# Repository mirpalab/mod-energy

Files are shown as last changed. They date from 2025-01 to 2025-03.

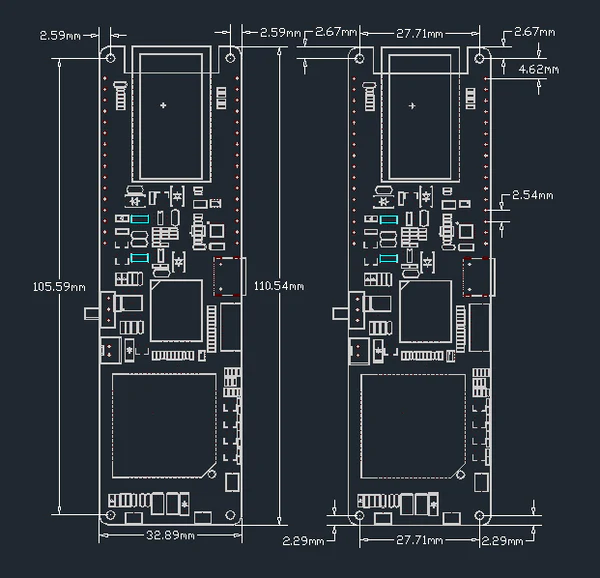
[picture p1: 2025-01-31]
images/quote esp32.png

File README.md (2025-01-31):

Ciò che si trova qui è scritto e gestito dal MIRPALab.

Viene fornito "così com'è", senza alcuna garanzia espressa o implicita di alcun tipo, incluse ma non limitate alle garanzie di commerciabilità, idoneità per uno scopo particolare e non violazione.

In nessun caso l'autore sarà ritenuto responsabile per qualsiasi reclamo, danno o altra responsabilità, sia in un'azione contrattuale, extracontrattuale o altro, derivante da, fuori da o in connessione con il codice o l'uso o altre transazioni nel codice.

Tutti i codici sono concessi in licenza con la GNU General Public License v3.0 (GPLv3).

È possibile usare, modificare e distribuire liberamente questo codice secondo i termini della GPLv3, che può essere trovata su: https://www.gnu.org/licenses/gpl-3.0.html

Utilizzando questo codice, si accetta di rispettare i termini della GPLv3.

Descrizione:

La cartella "sketch" contiene il codice Arduino che deve essere caricato sulla scheda ESP32; in "stl_files" ci sono tre progetti 3D per il case esterno e per l'alloggiamento del sensore.
Se si vuole usare un case generico, in "images" si troveranno tutte le misure per i fori che devono essere fatti.

MIRPALab.it

--------------------------------------------------

What you find here is written and maintained by MIRPALab.

It is provided "as is", without any express or implied warranty of any kind, including but not limited to the warranties of merchantability, fitness for a particular purpose, and non-infringement.

In no event shall the author be liable for any claim, damages, or other liability, whether in an action of contract, tort, or otherwise, arising from, out of, or in connection with the code or the use or other dealings in the code.

All codes are licensed under the GNU General Public License v3.0 (GPLv3).

You may freely use, modify, and distribute this code under the terms of the GPLv3, which can be found at: https://www.gnu.org/licenses/gpl-3.0.html

By using this code, you agree to comply with the terms of the GPLv3.

Description:

Folder "sketch" contains the Arduino code that you have to upload to ESP32 board; in "stl_files" there are three 3D projects for the external case and for sensor enclosure.
If you want to use a generic case, in "images" you'll find all measurements for the holes that need to be made.

MIRPALab.it

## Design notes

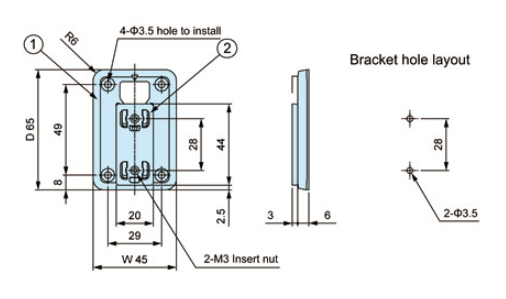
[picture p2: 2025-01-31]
images/quote slitta.png

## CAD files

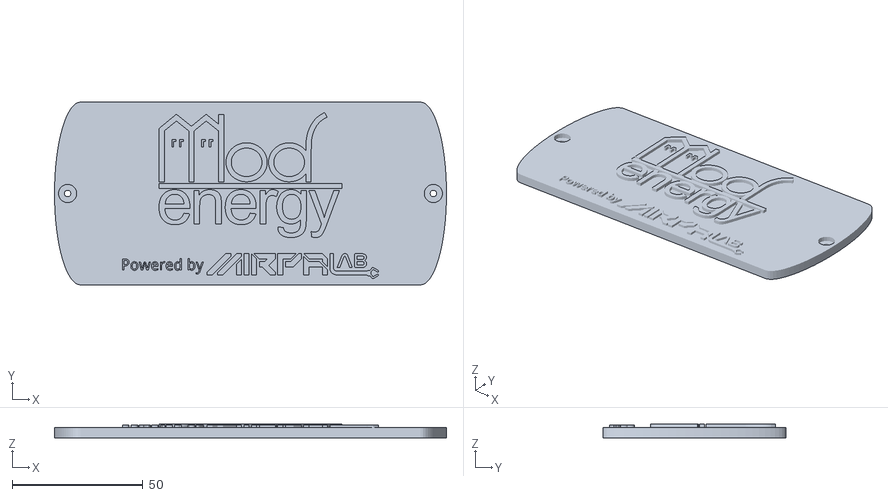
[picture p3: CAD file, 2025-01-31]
stl_files/sensor_case_cover.stl
150.0 x 70.0 x 5.33

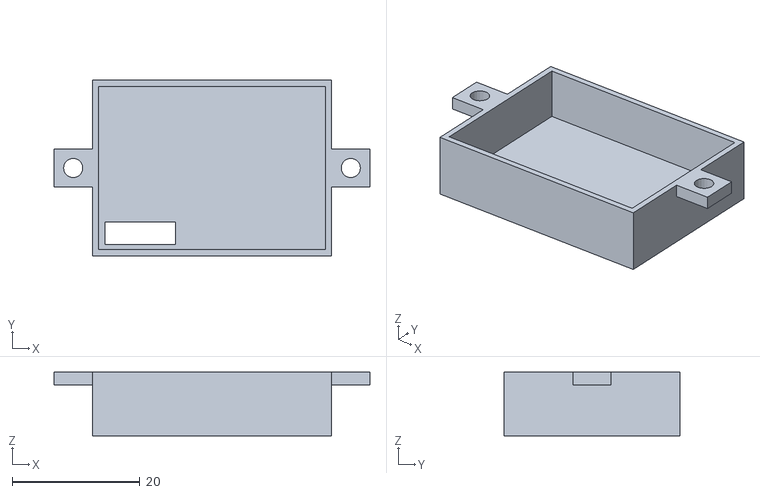
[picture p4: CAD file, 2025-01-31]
stl_files/sensor_enclosure.stl
49.5 x 27.5 x 10.0

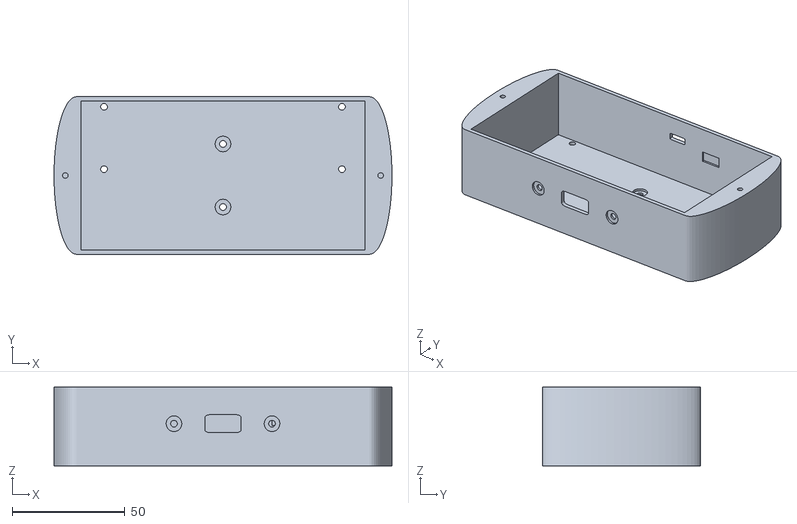
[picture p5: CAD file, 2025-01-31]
stl_files/sensor_external_case.stl
150.0 x 70.0 x 35.0

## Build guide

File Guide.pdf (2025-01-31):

ISTRUZIONI PER L’ASSEMBLAGGIO DELL’UNITÀ SENSORI

- LISTA DEI MATERIALI
- Una (1) board ESP32 LILYGO T-A7670E/G con antenna LTE;
- Un (1) sensore integrato SENSIRION SCD-30;
- Una (1) staffa di montaggio a parete MISUMI WM-1W;
- Una (1) batteria LG INR 18650-MJ1 3500mAh – 10A;
- Una (1) SIM 4G con piano dati;
- Un (1) alimentatore USB-C Raspberry Pi 5.1V 3.0A;
- Dodici (12) viti M3 da 6mm;
- Due (2) dadi M3;
- Quattro (4) distanziali M3 da 20mm;
- Tre (3) file .stl per stampare l’involucro e il case per alloggiare il sensore o, in alternativa, scatola di derivazione in ABS IP65 da 158x90x60mm.

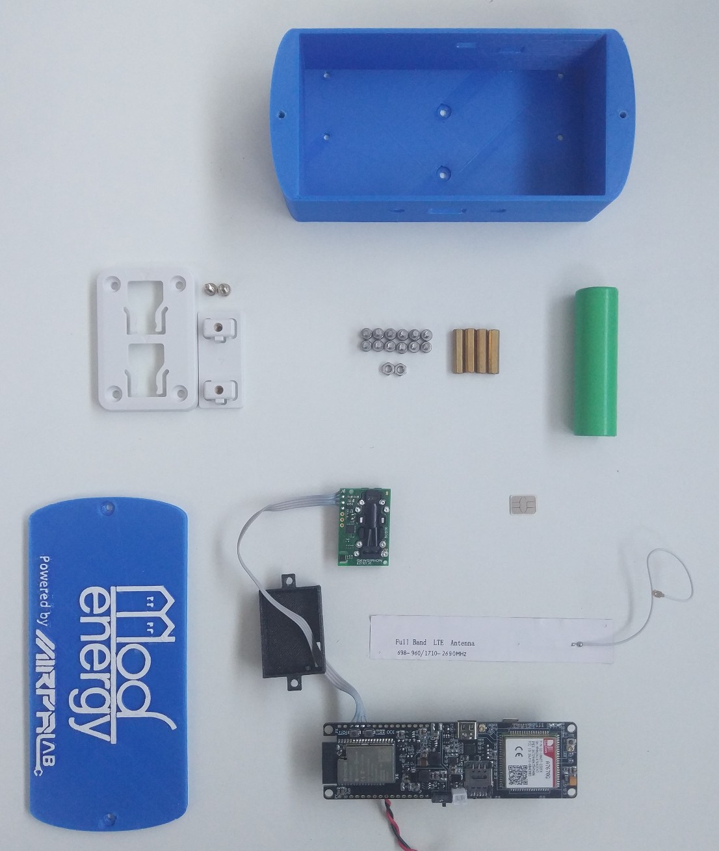
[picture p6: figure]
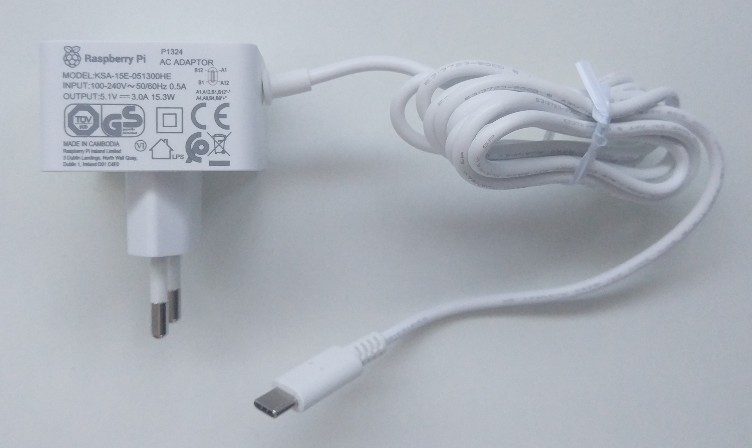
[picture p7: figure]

- ASSEMBLAGGIO DELL’UNITÀ
1. Montaggio dell’unità utilizzando i file .stl (scaricabili al seguente link) (https://github.com/mirpalab/mod-energy/tree/main/stl_files)

1.1 Avvitare il supporto della staffa sul retro del contenitore mediante l’utilizzo delle viti M3 in dotazione:

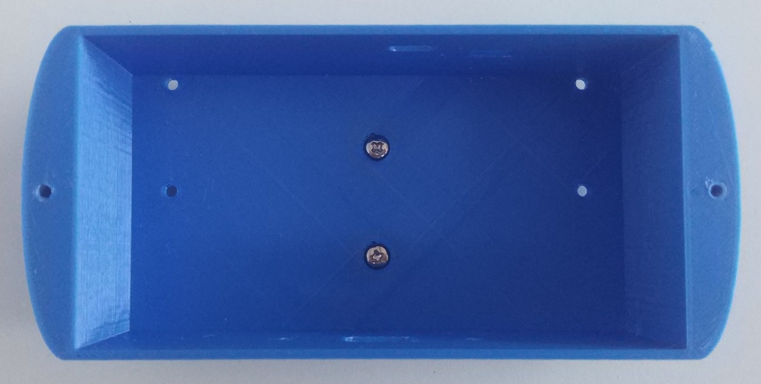
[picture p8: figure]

1.2 Assicurarsi che il verso di montaggio sia quello indicato in foto, con la freccia che punta verso la parte inferiore dell’unità:

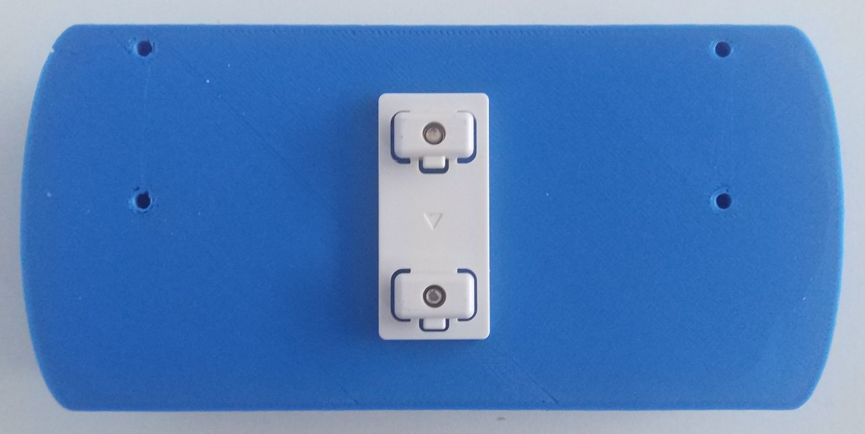
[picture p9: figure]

1.3 Installare l’antenna LTE in dotazione nel kit ESP32 rimuovendo il liner:

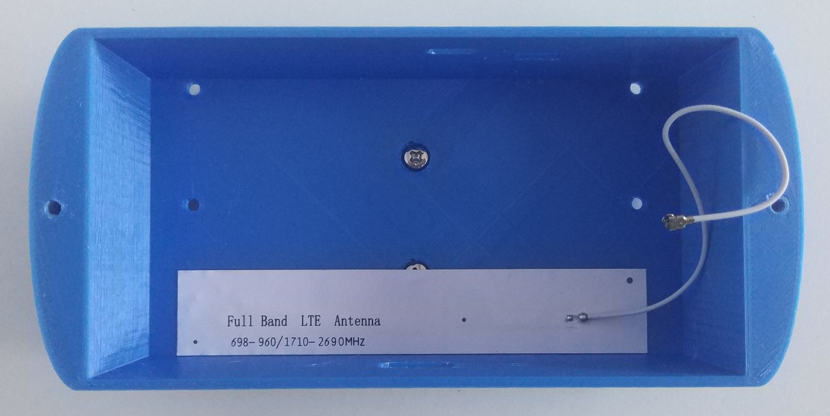
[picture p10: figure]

1.4 Saldare 4 cavi (si raccomanda una lunghezza pari o superiore a 75mm) al sensore, rispettivamente a VIN, GND, SCL e SDA:

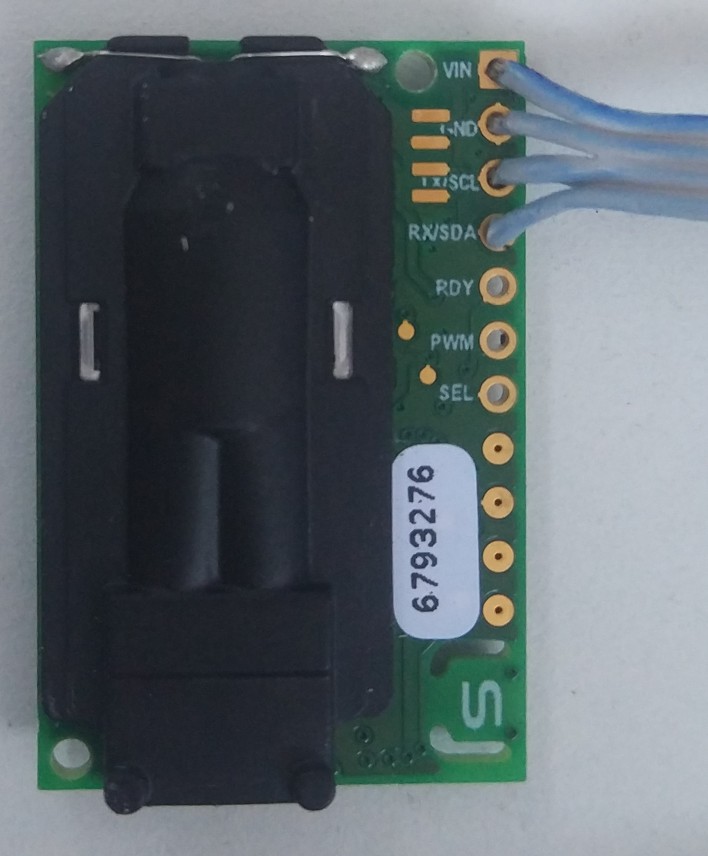
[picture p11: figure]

1.5 Stampare e montare ad incastro la scocca per isolare il sensore:

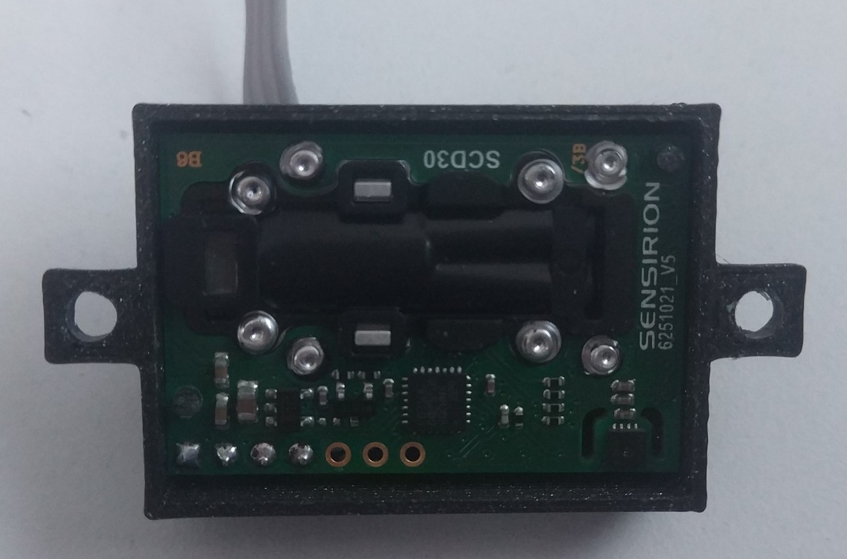
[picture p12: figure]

1.6 Saldare l’altra estremità dei cavi ad ESP32, rispettivamente a VDD3V3, GND, IO22 (SCL) ed IO21 (SDA):

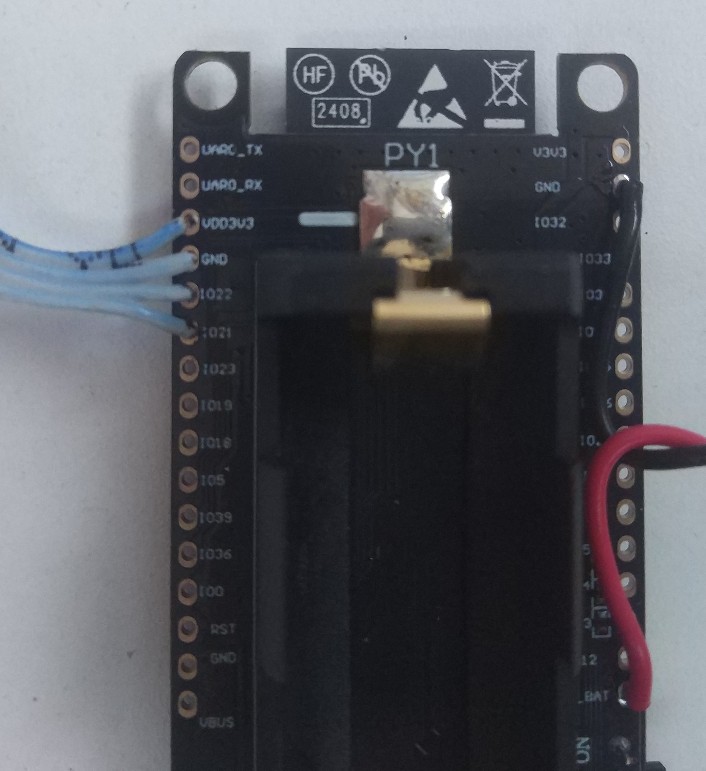
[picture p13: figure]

1.7 Montare i 4 distanziali da 20mm sui fori della board ESP32:

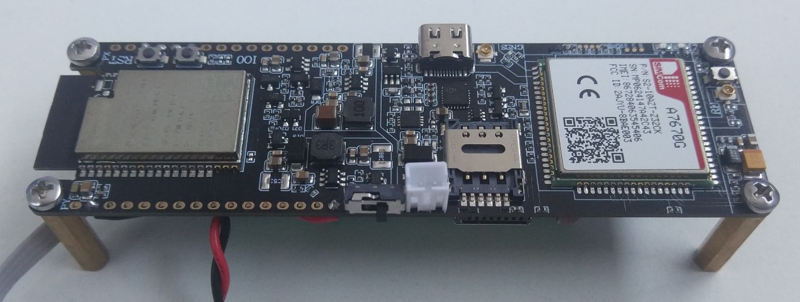
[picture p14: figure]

1.8 Inserire la batteria assicurandosi di rispettare la polarità:

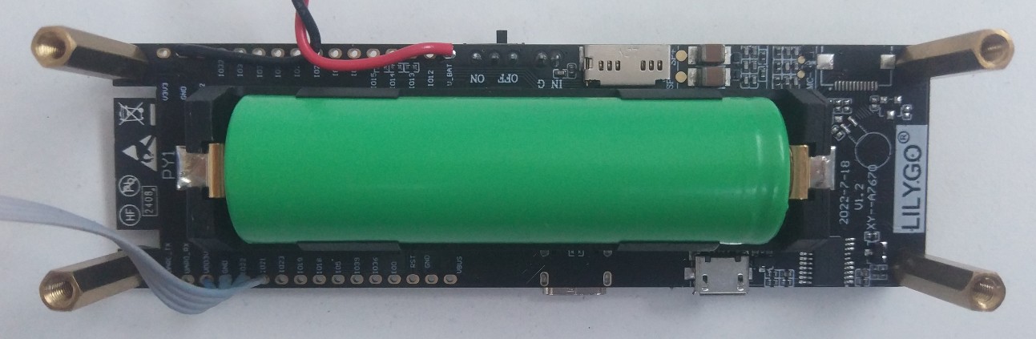
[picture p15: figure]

Nota: Assicurarsi che l’interruttore sia posizionato su “OFF”.

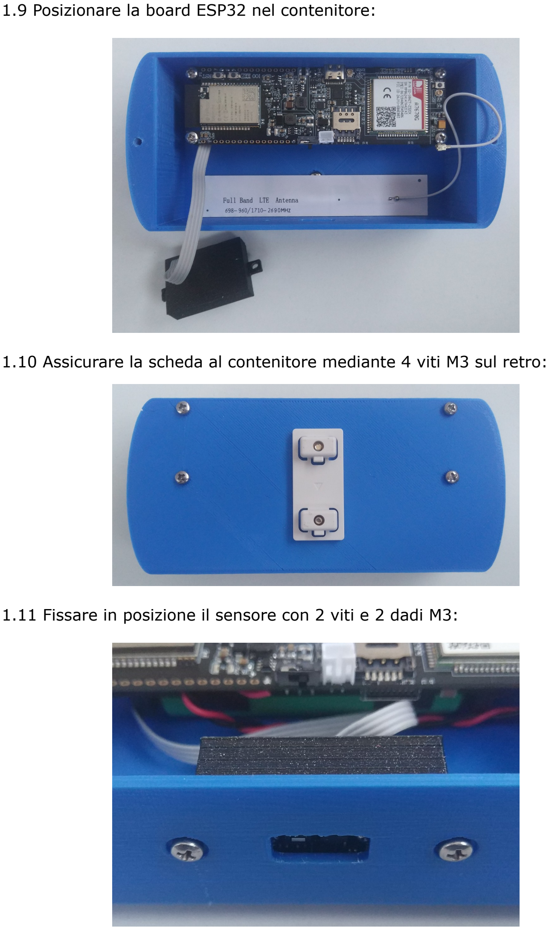
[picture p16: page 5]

1.9 Posizionare la board ESP32 nel contenitore:

1.10 Assicurare la scheda al contenitore mediante 4 viti M3 sul retro:

1.11 Fissare in posizione il sensore con 2 viti e 2 dadi M3:

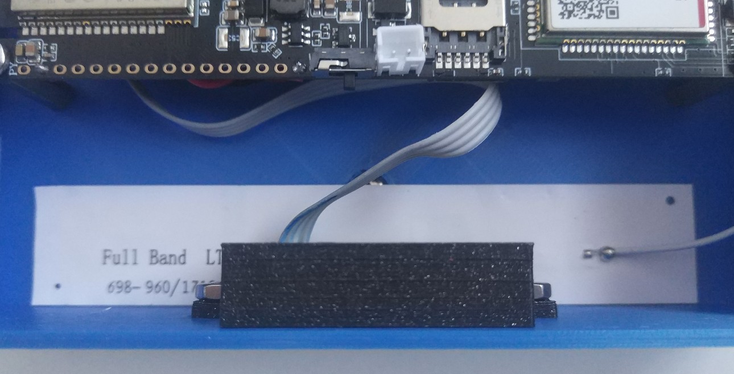
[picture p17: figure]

1.12 Connettere l’antenna LTE alla board ESP32:

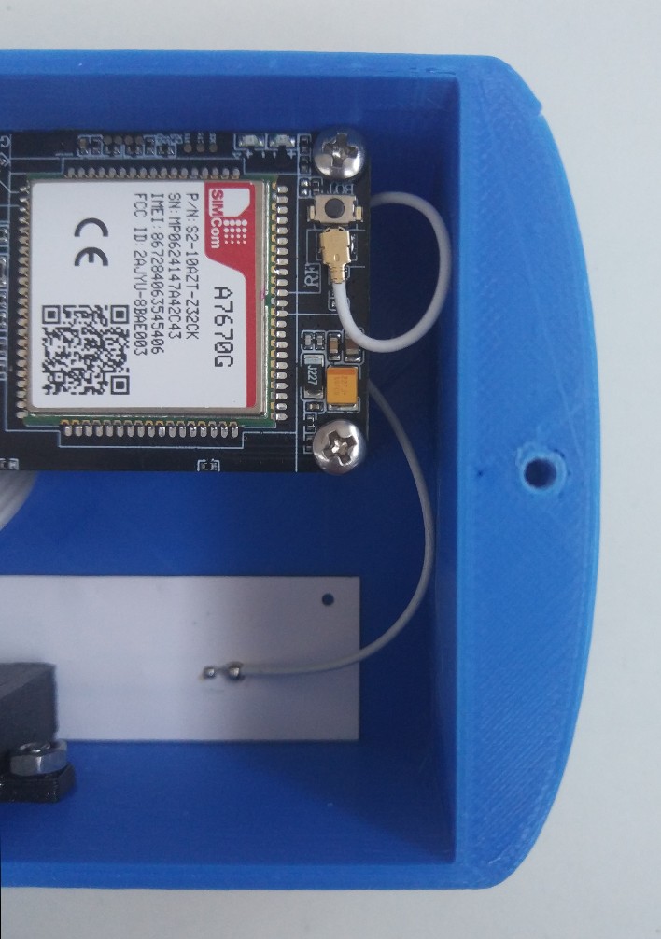
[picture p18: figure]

1.13 Sbloccare la slitta della scheda SIM verso il basso ed inserire la SIM 4G, dopo aver rimosso il codice PIN di blocco dalla stessa (qualora presente):

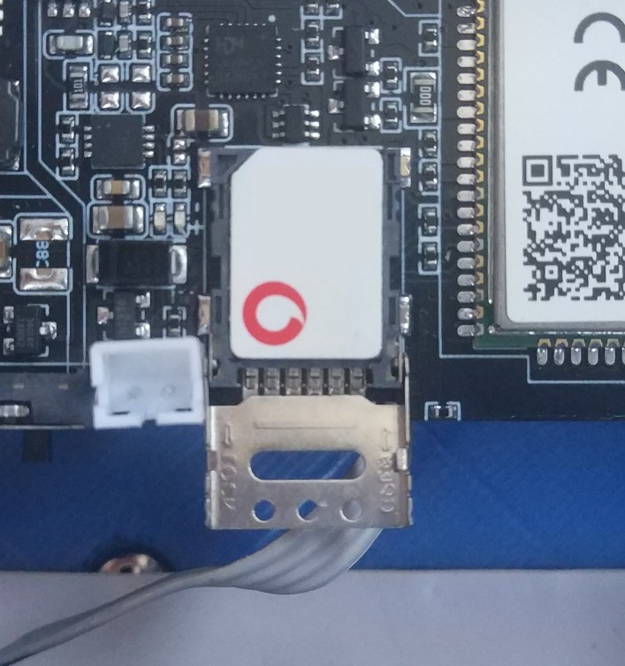
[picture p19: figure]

1.14 Richiudere la slitta assicurando la SIM 4G in posizione:

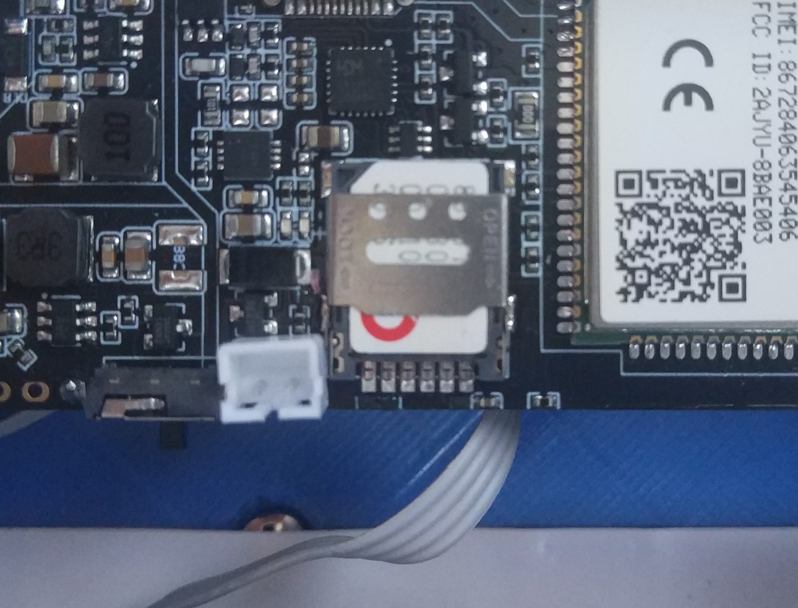
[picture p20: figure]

1.15 Chiudere il contenitore utilizzando il coperchio e 2 viti M3:

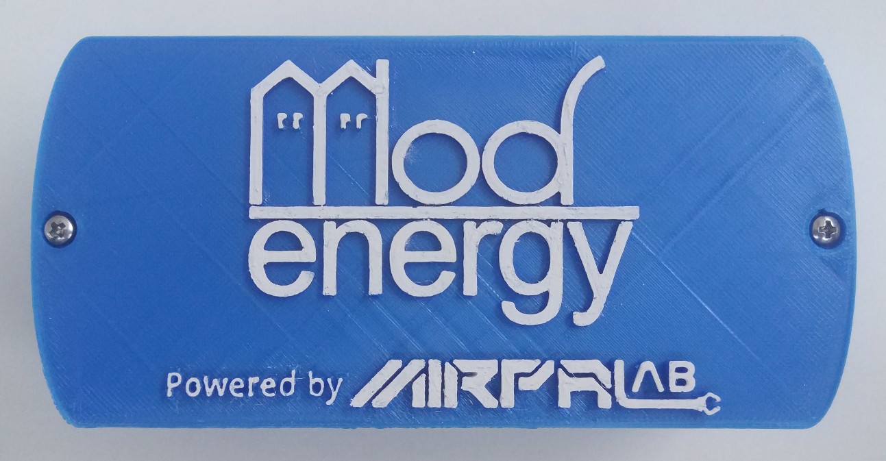
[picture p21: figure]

2. Montaggio dell’unità utilizzando un contenitore generico

Per effettuare il montaggio su un contenitore generico occorre seguire le medesime istruzioni scritte precedentemente, avendo cura di forare il contenitore seguendo le quote dei fori mostrate di seguito.

Il foro di comunicazione del sensore con l’esterno non deve essere inferiore a 16x8mm.

Si raccomanda, ad ogni modo, di utilizzare la scocca fornita nel file .stl per isolare il sensore, in modo da renderlo immune da interferenze termiche circostanti che potrebbero falsare le letture del sensore stesso.

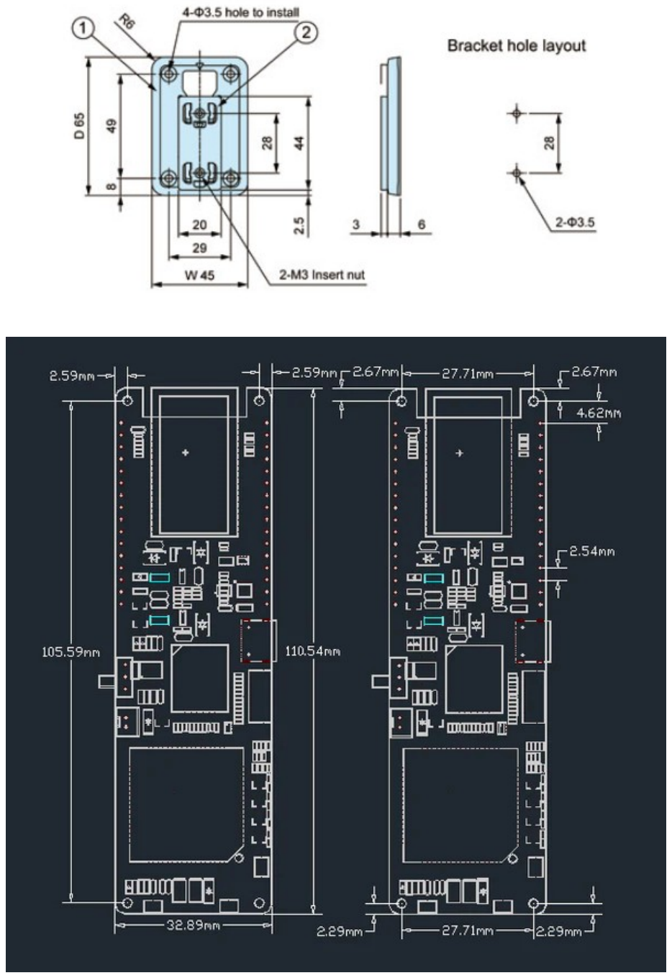
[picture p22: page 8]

3. Programmazione della scheda ESP32

Per una maggiore semplicità di programmazione, si è ricorso all’utilizzo dell’IDE Arduino; per programmare correttamente la board occorre installare:

- Driver CH9102 USB Bridge; (https://cdn-learn.adafruit.com/assets/assets/000/120/907/original/CH343SER.ZIP?1683669881)
- Arduino IDE 1.8 (la versione 2 non è pienamente compatibile con le board ESP32 e le librerie che andranno installate), scaricabile dal Microsoft Store o, in alternativa, dal seguente link; (https://downloads.arduino.cc/arduino-1.8.19-windows.exe)
- Arduino ESP32, seguendo le istruzioni presenti al seguente link. (https://docs.espressif.com/projects/arduino-esp32/en/latest/installing.html)

In Arduino IDE, mediante il menu Strumenti Gestione librerie… installare: →
- Libreria Sensirion I2C SCD30 (con le relative dipendenze);
- Libreria TinyGSM;
- Libreria ArduinoHttpClient.

Una volta installato quanto sopra, basta collegare il dispositivo tramite la porta USB-C al computer, facendo attenzione a non installare ulteriori librerie o aggiornare quelle già installate ed impostare i seguenti parametri nel menu Strumenti:

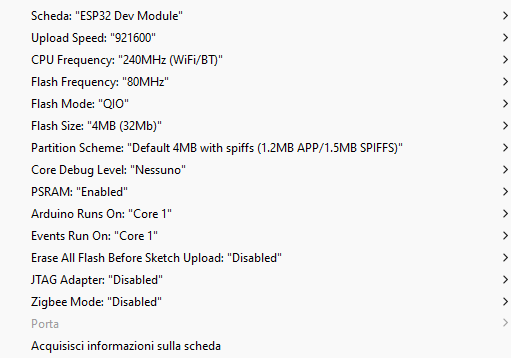
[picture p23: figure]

Il codice per programmare ESP32 è disponibile al seguente link. (https://github.com/mirpalab/mod-energy) Cercare nel codice la riga seguente:

È necessario specificare, per ogni unità, un ID univoco cambiando il parametro tra i doppi apici; nel dettaglio:

- 4 unità dovranno avere come identificativo la lettera A seguita da numeri crescenti (“A1”, “A2”, “A3”, “A4”);
- 6 unità dovranno avere come identificativo la lettera B seguita da numeri crescenti (“B1”, “B2”, “B3”, “B4”, “B5”, “B6”);
- 4 unità dovranno avere come identificativo la lettera C seguita da numeri crescenti (“C1”, “C2”, “C3”, “C4”);
- 6 unità dovranno avere come identificativo la lettera D seguita da numeri crescenti (“D1”, “D2”, “D3”, “D4”, “D5”, “D6”);
- 3 unità dovranno avere come identificativo la lettera E seguita da numeri crescenti (“E1”, “E2”, “E3”);
- 3 unità dovranno avere come identificativo la lettera F seguita da numeri crescenti (“F1”, “F2”, “F3”);
- 2 unità dovranno avere come identificativo la lettera G seguita da numeri crescenti (“G1”, “G2”);
- 2 unità dovranno avere come identificativo la lettera H seguita da numeri crescenti (“H1”, “H2”).

Nota: Tali ID andranno riportati inoltre, mediante etichetta stampata, internamente ad ogni unità in una posizione favorevole alla lettura, nonché all’esterno dell’involucro al fine di facilitare eventuali interventi di manutenzione straordinaria.

Una volta aperto lo sketch sulla IDE, occorre compilarlo e caricarlo su ESP32. In certi casi può capitare, durante la prima compilazione, che appaiano dei messaggi di warning; tali avvisi non sono bloccanti poiché evidenziano semplicemente alcune funzioni deprecate nella libreria del sensore, di conseguenza l’IDE procederà a caricare il codice nella board senza problemi di sorta.

- INSTALLAZIONE DELL’UNITÀ

All’atto di installazione delle unità occorre, una volta posizionata la slitta e fatta scorrere l’unità su di essa fino ad ottenere un perfetto ancoraggio, svitare le viti che tengono in sede il coperchio e commutare l’interruttore di accensione di ESP32 su “ON”, dopo di che si può provvedere a richiudere l’unità e a collegarla ad una presa di corrente mediante alimentatore USB-C.
Il dispositivo, una volta alimentato, inizierà a rilevare i dati ambientali ed a salvarli in una memoria volatile; in caso di disservizi sulla rete elettrica, la batteria installata permetterà la conservazione dei dati acquisiti fino ad un massimo di cinque (5) giorni.

La presente guida, insieme al codice, le immagini e i file .stl, è consultabile qui. (https://github.com/mirpalab/mod-energy/)

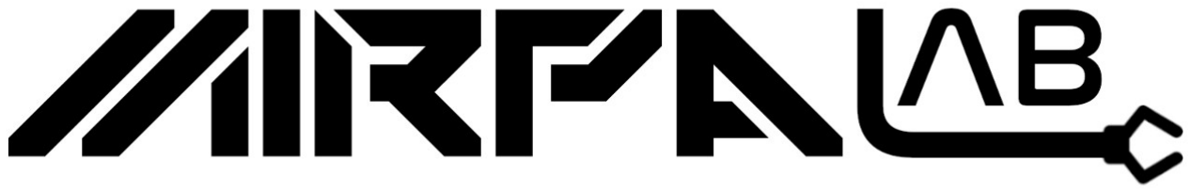
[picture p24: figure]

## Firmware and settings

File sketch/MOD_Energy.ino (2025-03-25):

// This firmware has been developed to be used on LilyGO-T-A7670E/G/SA R2 platforms in
// combination with a Sensirion SCD30 sensor. The device is responsible for detecting
// data related to temperature, relative humidity, and CO2 concentration at regular
// intervals, as well as transmitting this data to an external server, via the
// integrated SIMCOM A7670 module. The code can be customized by modifying the device ID,
// the APN parameters of the mobile network operator, the duration of deep sleep between
// measurements, the server address, and the string to be sent via a GET request.

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
// Board model
#define LILYGO_T_A7670

// Select radio modem
#define TINY_GSM_MODEM_A7670

// Set RX buffer to 1KB
#define TINY_GSM_RX_BUFFER 1024

// I2C pins
#define I2C_SDA                             (21)
#define I2C_SCL                             (22)
#define I2C_CLKRATE_50K                     (50000)

// LilyGO T-A7670G Pinout
#define MODEM_BAUDRATE                      (115200)
#define MODEM_DTR_PIN                       (25)
#define MODEM_TX_PIN                        (26)
#define MODEM_RX_PIN                        (27)
// The modem boot pin needs to follow the startup sequence.
#define BOARD_PWRKEY_PIN                    (4)
#define BOARD_ADC_PIN                       (35)
// The modem power switch must be set to HIGH for the modem to supply power.
#define BOARD_POWERON_PIN                   (12)
#define MODEM_RING_PIN                      (33)
#define MODEM_RESET_PIN                     (5)
#define BOARD_MISO_PIN                      (2)
#define BOARD_MOSI_PIN                      (15)
#define BOARD_SCK_PIN                       (14)
#define BOARD_SD_CS_PIN                     (13)
#define BOARD_BAT_ADC_PIN                   (35)
#define MODEM_RESET_LEVEL                   HIGH

#define TINY_GSM_USE_GPRS true
#define TINY_GSM_USE_WIFI false

// Set serial for modem debug console (to the Serial Monitor, default speed 115200)
#define SerialMon Serial
#define SerialAT Serial1

#include <TinyGsmClient.h>
#include <ArduinoHttpClient.h>
#include <Wire.h>
#include <SensirionI2cScd30.h>

// Define the serial console for modem debug prints, if needed
#define TINY_GSM_DEBUG SerialMon

// Set device ID
String deviceID = "00";

// Set APN Details / GPRS credentials
const char apn[] = "apn.vianova.it";
const char gprsUser[] = "";
const char gprsPass[] = "";

// Define a conversion from microseconds to seconds
uint64_t us_to_s = 1000000;

// Set deep sleep timer to 3600 seconds in order to have a measure each hour
uint64_t time_to_sleep = 3600;

// Set sensor error message
static int16_t geterr;
static int16_t measerror;
static char errorMessage[128];

// Save our counter to RTCRAM
RTC_DATA_ATTR int count = 0;

// Save boolean value of a GET request result
RTC_DATA_ATTR bool attemptGET;

// Define a struct that will hold all measurements done in 24 hours
typedef struct
{
  float temperature;
  float humidity;
  float co2Concentration;
} sensorReadings;

// Set number of readings to hold in memory
#define maxReadings 24

// Declare an array "Readings" of type "sensorReadings" with size "maxReadings" 
RTC_DATA_ATTR sensorReadings Readings[maxReadings];

void setup()
{
  Serial.begin(115200);

// Set clock frequency to 10MHz in order to save energy
  setCpuFrequencyMhz(10);
  Serial.println("Waking up");
  Serial.print("Clock speed set at ");
  Serial.print(getCpuFrequencyMhz());
  Serial.println(" MHz");

// Keep the GSM modem turned off while taking measurements
  TinyGsm modem(SerialAT);
  modem.poweroff();

// Initialize sensor
  SensirionI2cScd30 sensor;
  while (!Serial)
  {
    delay(1000);
  }
  Wire.begin();
  Wire.setClock(I2C_CLKRATE_50K);
  sensor.begin(Wire, SCD30_I2C_ADDR_61);
  sensor.startPeriodicMeasurement(0);
  float temperature = 0.0;
  float humidity = 0.0;
  float co2Concentration = 0.0;

// Measurements fail-safe: if, for any reasons, the sensor doesn't take a measurement, it tries again up to 5 times
  int attemptData = 0;
  do
  {
    measerror = sensor.blockingReadMeasurementData(co2Concentration, temperature, humidity);
    if (measerror != NO_ERROR)
    {
      Serial.print("Error trying to execute blockingReadMeasurementData(): ");
      errorToString(measerror, errorMessage, sizeof errorMessage);
      Serial.println(errorMessage);
      delay(2000);
      attemptData++;
    }
  }
  while (measerror != NO_ERROR && attemptData < 5);

// Assign measurements in an array
  Readings[count].temperature = temperature;
  Readings[count].humidity = humidity;
  Readings[count].co2Concentration = co2Concentration;
  count++;
  delay(2000);
    sensor.stopPeriodicMeasurement();

// Print number of counter on serial monitor and wake up with the main timer (3600s)
  if (count < 25)
  {    
    Serial.println("Measure #"+String(count));
    esp_sleep_enable_timer_wakeup(time_to_sleep * us_to_s);
  }
  else
  {
    Serial.println("Starting data trasmission routine...");

// When count is equal or greater than 25, the device will have acquired 24 measurements and will send the response to the server.
// The device wakes up for the 25th time, sends 24 measures, takes a 25th measure but immediately restarts in order to clear RTCRAM
// A GET request fail-safe has been implemented so if a GET fails, ESP32 will go to deep sleep: after this "soft reset" the counter
// will increment; nonetheless, when the value is equal or greater than 25, ESP32 must send measurement data to the server.

// Server details
    String server = "mod-energy-unipa.oa.r.appspot.com";
    String resource = "/writeday?id="+String(deviceID)
    +"&t_00="+String(Readings[0].temperature)+"&h_00="+String(Readings[0].humidity)+"&c_00="+String(Readings[0].co2Concentration)
    +"&t_01="+String(Readings[1].temperature)+"&h_01="+String(Readings[1].humidity)+"&c_01="+String(Readings[1].co2Concentration)
    +"&t_02="+String(Readings[2].temperature)+"&h_02="+String(Readings[2].humidity)+"&c_02="+String(Readings[2].co2Concentration)
    +"&t_03="+String(Readings[3].temperature)+"&h_03="+String(Readings[3].humidity)+"&c_03="+String(Readings[3].co2Concentration)
    +"&t_04="+String(Readings[4].temperature)+"&h_04="+String(Readings[4].humidity)+"&c_04="+String(Readings[4].co2Concentration)
    +"&t_05="+String(Readings[5].temperature)+"&h_05="+String(Readings[5].humidity)+"&c_05="+String(Readings[5].co2Concentration)
    +"&t_06="+String(Readings[6].temperature)+"&h_06="+String(Readings[6].humidity)+"&c_06="+String(Readings[6].co2Concentration)
    +"&t_07="+String(Readings[7].temperature)+"&h_07="+String(Readings[7].humidity)+"&c_07="+String(Readings[7].co2Concentration)
    +"&t_08="+String(Readings[8].temperature)+"&h_08="+String(Readings[8].humidity)+"&c_08="+String(Readings[8].co2Concentration)
    +"&t_09="+String(Readings[9].temperature)+"&h_09="+String(Readings[9].humidity)+"&c_09="+String(Readings[9].co2Concentration)
    +"&t_10="+String(Readings[10].temperature)+"&h_10="+String(Readings[10].humidity)+"&c_10="+String(Readings[10].co2Concentration)
    +"&t_11="+String(Readings[11].temperature)+"&h_11="+String(Readings[11].humidity)+"&c_11="+String(Readings[11].co2Concentration)
    +"&t_12="+String(Readings[12].temperature)+"&h_12="+String(Readings[12].humidity)+"&c_12="+String(Readings[12].co2Concentration)
    +"&t_13="+String(Readings[13].temperature)+"&h_13="+String(Readings[13].humidity)+"&c_13="+String(Readings[13].co2Concentration)
    +"&t_14="+String(Readings[14].temperature)+"&h_14="+String(Readings[14].humidity)+"&c_14="+String(Readings[14].co2Concentration)
    +"&t_15="+String(Readings[15].temperature)+"&h_15="+String(Readings[15].humidity)+"&c_15="+String(Readings[15].co2Concentration)
    +"&t_16="+String(Readings[16].temperature)+"&h_16="+String(Readings[16].humidity)+"&c_16="+String(Readings[16].co2Concentration)
    +"&t_17="+String(Readings[17].temperature)+"&h_17="+String(Readings[17].humidity)+"&c_17="+String(Readings[17].co2Concentration)
    +"&t_18="+String(Readings[18].temperature)+"&h_18="+String(Readings[18].humidity)+"&c_18="+String(Readings[18].co2Concentration)
    +"&t_19="+String(Readings[19].temperature)+"&h_19="+String(Readings[19].humidity)+"&c_19="+String(Readings[19].co2Concentration)
    +"&t_20="+String(Readings[20].temperature)+"&h_20="+String(Readings[20].humidity)+"&c_20="+String(Readings[20].co2Concentration)
    +"&t_21="+String(Readings[21].temperature)+"&h_21="+String(Readings[21].humidity)+"&c_21="+String(Readings[21].co2Concentration)
    +"&t_22="+String(Readings[22].temperature)+"&h_22="+String(Readings[22].humidity)+"&c_22="+String(Readings[22].co2Concentration)
    +"&t_23="+String(Readings[23].temperature)+"&h_23="+String(Readings[23].humidity)+"&c_23="+String(Readings[23].co2Concentration);

// GSM MODULE PARAMETERS AND FUNCTIONS BLOCK
    TinyGsm modem(SerialAT);
    TinyGsmClient client(modem);
    HttpClient http(client, server);

// Set Serial Monitor baud rate
    SerialMon.begin(115200);
    delay(10);

// Turn on DC boost to power on the modem
    #ifdef BOARD_POWERON_PIN
    pinMode(BOARD_POWERON_PIN, OUTPUT);
    digitalWrite(BOARD_POWERON_PIN, HIGH);
    #endif

// Set modem reset
    pinMode(MODEM_RESET_PIN, OUTPUT);
    digitalWrite(MODEM_RESET_PIN, !MODEM_RESET_LEVEL);
  
// Turn on modem
    pinMode(BOARD_PWRKEY_PIN, OUTPUT);
    digitalWrite(BOARD_PWRKEY_PIN, LOW);
    delay(100);
    digitalWrite(BOARD_PWRKEY_PIN, HIGH);
    delay(1000);
    digitalWrite(BOARD_PWRKEY_PIN, LOW);

    SerialMon.println("Wait...");

// Set GSM module baud rate and pins
    SerialAT.begin(MODEM_BAUDRATE, SERIAL_8N1, MODEM_RX_PIN, MODEM_TX_PIN);
    Serial.println("Starting modem...");
    delay(3000);
    SerialMon.println(F("Initializing modem..."));
    if (!modem.init())
    {
      SerialMon.println(F("Failed to restart modem, delaying 10s and retrying"));
      return;
    }

    #if TINY_GSM_USE_GPRS
// GPRS connection parameters are usually set after network registration
    SerialMon.print(F("Connecting to "));
    SerialMon.print(apn);

// Network fail-safe: if, for any reasons, the radio module doesn't connect to a GSM network, it tries again up to 5 times
    int attemptGPRS = 0;
    do
    {
      if (!modem.gprsConnect(apn, gprsUser, gprsPass))
      {
        SerialMon.println(": Fail");
        delay(5000);
        attemptGPRS++;
        SerialMon.print("Retry... ");
      }
      else
      {
        SerialMon.println(": Success");
      }
    }
    while (!modem.gprsConnect(apn, gprsUser, gprsPass) && attemptGPRS < 5);

    if (modem.isGprsConnected())
    {
      SerialMon.println("GPRS connected");
    }
    #endif

// The following code is needed for HTTPS
    http.connectionKeepAlive();

// Connection timeout set to 90 seconds
    http.setTimeout(9000);
    SerialMon.print(F("Performing HTTP GET request... "));

// GET fail-safe: if, for any reasons, a GET request fails, it tries again until it succeeds
    do
    {
      geterr = http.get(resource);
      if (geterr != 0)
      {
        attemptGET = false;
        SerialMon.println(F("GET request failed"));
        esp_sleep_enable_timer_wakeup(10 * us_to_s);
        esp_deep_sleep_start();
      }
      else
      {
        attemptGET = true;
        SerialMon.println(F("GET request succeeded"));
      }
    }
    while (geterr != 0 && attemptGET == false);

    int status = http.responseStatusCode();
    SerialMon.print(F("Response status code: "));
    SerialMon.println(status);
    if (!status)
    {
      delay(1000);
      return;
    }

// Shutdown
    http.stop();
    SerialMon.println(F("Server disconnected"));

    #if TINY_GSM_USE_GPRS
    modem.gprsDisconnect();
    SerialMon.println(F("GPRS disconnected"));
    modem.poweroff();
    #endif

// Restart ESP32 in order to clear RTCRAM
    Serial.println("Restarting ESP32 in order to clear RTCRAM...");
    delay(1000);
    esp_restart();
  }

// Go back to deep sleep
  Serial.println("Going to sleep");
  esp_deep_sleep_start();
}

void loop()
{
// No code here  
}

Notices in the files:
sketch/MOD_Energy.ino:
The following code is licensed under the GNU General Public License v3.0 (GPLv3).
